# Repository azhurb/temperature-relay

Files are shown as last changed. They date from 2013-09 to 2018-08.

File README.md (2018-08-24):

# Smart outlet

Outlet controlled by a temperature sensor using *ATmega8-P*.  
The heater can be connected to the smart outlet and it will act as a thermostat.

## Demo
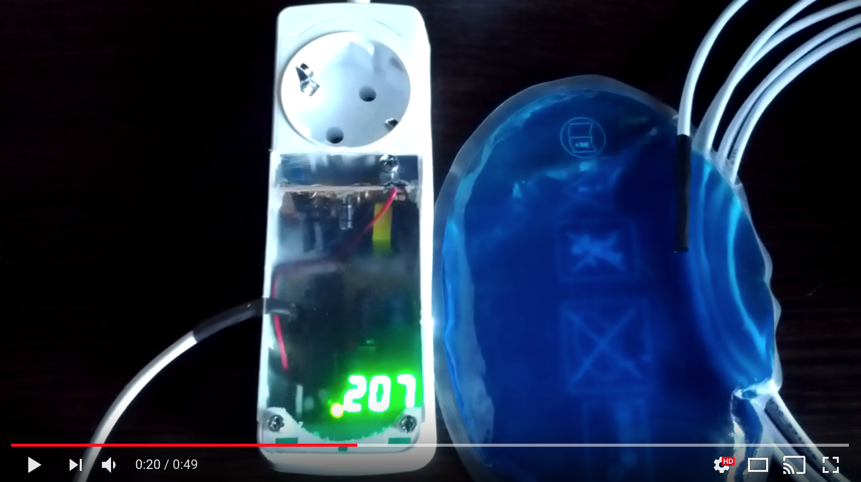
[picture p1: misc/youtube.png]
Outlet controlled by a temperature sensor using ATmega8-P (https://www.youtube.com/watch?v=Genm2P_8VqQ)


## License
Licensed under the MIT license.

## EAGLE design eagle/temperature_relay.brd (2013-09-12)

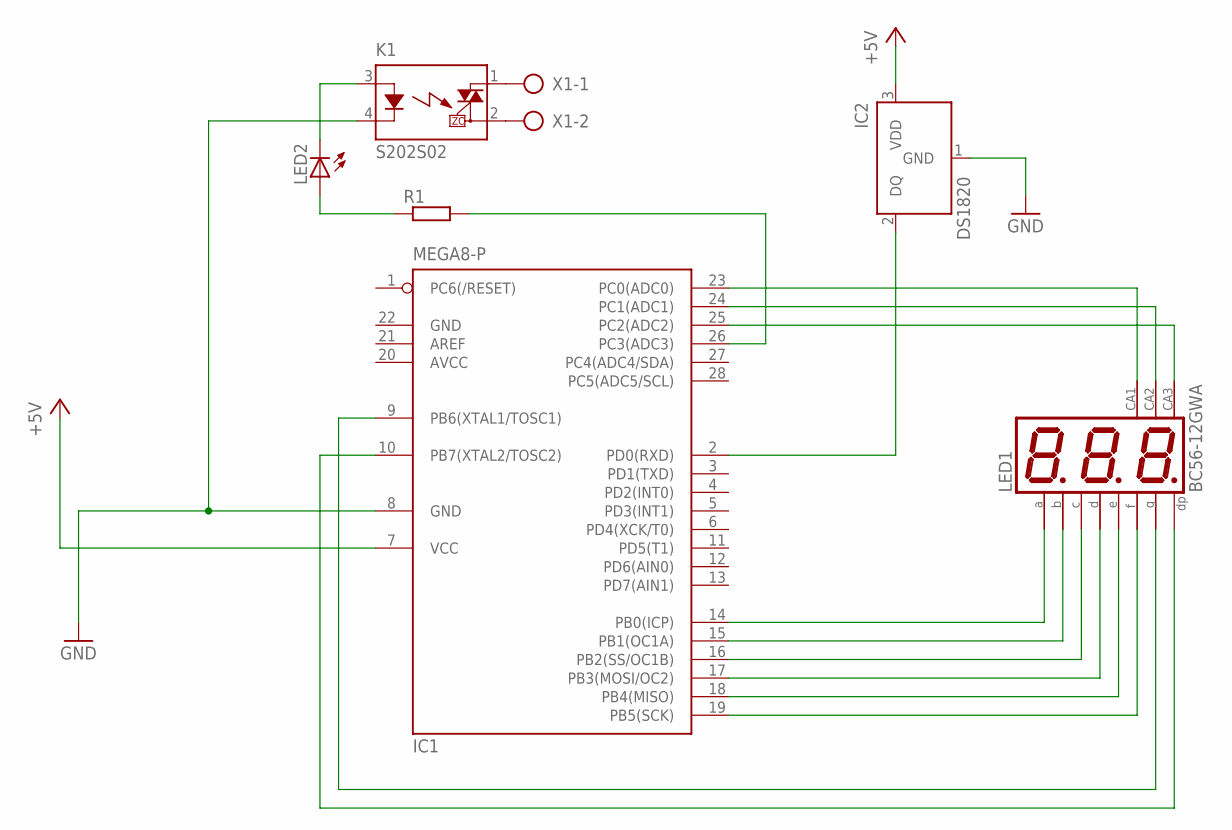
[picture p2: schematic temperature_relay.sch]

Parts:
IC1: MEGA8-P; DIL28-3
IC2: DS1820; TO-92
K1: S202S02
LED1: BC56-12GWA; BX56-12
LED2: LED5MM
R1: R-EU_0309/12; 0309/12
X1: AK300/2

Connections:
+5V: IC1.7 (VCC), IC2.3 (VDD)
AVCC: IC1.20 (AVCC)
GND: IC1.8 (GND), IC1.22 (GND), IC2.1 (GND), K1.4 (K)
unnamed: IC1.23 (PC0(ADC0)), LED1.12 (CA)
unnamed: IC1.24 (PC1(ADC1)), LED1.9 (CA)
unnamed: IC1.25 (PC2(ADC2)), LED1.8 (CA)
unnamed: IC1.14 (PB0(ICP)), LED1.11 (A)
unnamed: IC1.15 (PB1(OC1A)), LED1.7 (B)
unnamed: IC1.16 (PB2(SS/OC1B)), LED1.4 (C)
unnamed: IC1.17 (PB3(MOSI/OC2)), LED1.2 (D)
unnamed: IC1.18 (PB4(MISO)), LED1.1 (E)
unnamed: IC1.19 (PB5(SCK)), LED1.10 (F)
unnamed: IC1.9 (PB6(XTAL1/TOSC1)), LED1.5 (G)
unnamed: IC1.10 (PB7(XTAL2/TOSC2)), LED1.3 (DP)
unnamed: IC1.2 (PD0(RXD)), IC2.2 (DQ)
unnamed: IC1.26 (PC3(ADC3)), R1.2
unnamed: LED2.A, R1.1
unnamed: K1.3 (A), LED2.K (C)
unnamed: K1.2 (DS2), X1.2
unnamed: K1.1 (DS1), X1.1

Board: 2 copper layers, 7 parts (0 on the bottom side), 19 nets, no tracks yet.

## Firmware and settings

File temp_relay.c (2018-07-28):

/***Использование динамической индикации***/
#include <avr/io.h>
#include <avr/interrupt.h>
#include <util/delay.h>

#include "delay.h"
#include "onewire.h"
#include "ds18x20.h"


char SEGMENT[ ] = {0x3F, 0x06, 0x5B, 0x4F, 0x66, 0x6D, 0x7D, 0x07, 0x7F, 0x6F};

volatile unsigned char segcounter = 0;
volatile int display1 = 0;

// Обработчик прерывания по переполнению таймера2
ISR (TIMER2_OVF_vect)
{    
	PORTB = 0x00; //гасим все разряды
	DDRC  = (1 << segcounter) | (PORTC & (1 << PC3)); //выбираем следующий разряд
	switch (segcounter)
	{     
		case 0:
			PORTB = SEGMENT[display1 % 1000 / 100]; // здесь раскладываем число на разряды
			break;
			case 1:
			PORTB = SEGMENT[display1 % 100 / 10] | 0x80;
			break;    
			case 2:
			PORTB = SEGMENT[display1 % 10];
			break;
		}
		if ((segcounter++) > 1) segcounter = 0;    
	}

unsigned char	nDevices;	// количество сенсоров
unsigned char	owDevicesIDs[MAXDEVICES][8];	// Их ID

unsigned char search_ow_devices(void) // поиск всех устройств на шине
{ 
	unsigned char	i;
	unsigned char	id[OW_ROMCODE_SIZE];
	unsigned char	diff, sensors_count;

	sensors_count = 0;

	for( diff = OW_SEARCH_FIRST; diff != OW_LAST_DEVICE && sensors_count < MAXDEVICES ; )
	{ 
		OW_FindROM( &diff, &id[0] );

		if( diff == OW_PRESENCE_ERR ) break;

		if( diff == OW_DATA_ERR )	break;

		for (i=0;i<OW_ROMCODE_SIZE;i++)
			owDevicesIDs[sensors_count][i] = id[i];

		sensors_count++;
	}
	return sensors_count;
}


/***Главная функция***/
int main (void) 
{
	DDRB |= (1 << PB6)|(1 << PB5)|(1 << PB4)|(1 << PB3)|(1 << PB2)|(1 << PB1)|(1 << PB0);
	DDRC |= (1 << PC3)|(1 << PC2)|(1 << PC1)|(1 << PC0);
	PORTB = 0x00;

	DDRD = 0b00000010; PORTD = 0b00000000;

	TIMSK |= (1 << TOIE2); // разрешение прерывания по таймеру2
	TCCR2 |= (1 << CS21); //предделитель на 8

	sei(); //глобально разрешаем прерывания

	timerDelayInit();

	nDevices = search_ow_devices(); // ищем все устройства

	unsigned char	data[2]; // переменная для хранения старшего и младшего байта данных
	char readResult;
	unsigned char	themperature[3]; // в этот массив будет записана температура

	while(1)
	{
		
		for (unsigned char i=0; i<nDevices; i++)
		{
			
			switch (owDevicesIDs[i][0])
			{

				case OW_DS18B20_FAMILY_CODE: { // если найден термодатчик DS18B20

					DS18x20_StartMeasureAddressed(owDevicesIDs[i]); // запускаем измерение
					timerDelayMs(800); // ждем минимум 750 мс, пока конвентируется температура

					readResult = DS18x20_ReadData(owDevicesIDs[i], data);

					if (readResult == 1){
						DS18x20_ConvertToThemperature(data, themperature); // преобразовываем температуру в человекопонятный вид

						display1 = themperature[1]*10 + themperature[2]/10;

						if (display1 < 200){
							PORTC |= (1 << PC3);
						}else if (display1 > 220){
							PORTC &= ~(1 << PC3);
						}
					}

				} break;
			}
		}
	}
}

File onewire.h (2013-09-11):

#ifndef ONEWIRE_H
#define ONEWIRE_H


#include <avr/io.h>


#define true 1
#define false 0

// Максимальное количество устройств на шине
#define MAXDEVICES 8

// Если для эмуляции шины используется USART
#define UART_AS_OneWire

// Если для эмуляции 1-wire не спольльзуется USART, но используется 2 пина (вход и выход)
#define OW_TWO_PINS

#ifdef UART_AS_OneWire
	#define USART_BAUDRATE_57600 (((F_CPU / (57600 * 8UL))) - 1)
	#define USART_BAUDRATE_115200 (((F_CPU / (115200 * 8UL))) - 1)
	#define USART_BAUDRATE_9600 (((F_CPU / (9600 * 8UL))) - 1)
#else
	#include <util/delay.h>
	#define OW_DDR DDRB
	#define OW_PORT PORTB
	#define OW_PIN PINB
	#ifndef OW_TWO_PINS //если используется один пин, укажите его номер
		#define OW_BIT 0
	#else // если используются 2 пина, укажите их номера
		#define OW_BIT_OUT 1
		#define OW_BIT_IN 0
	#endif
#endif

#define OW_CMD_SEARCHROM	0xF0
#define OW_CMD_READROM		0x33
#define OW_CMD_MATCHROM		0x55
#define OW_CMD_SKIPROM		0xCC

#define	OW_SEARCH_FIRST	0xFF		// start new search
#define	OW_PRESENCE_ERR	0xFF
#define	OW_DATA_ERR	    0xFE
#define OW_LAST_DEVICE	0x00		// last device found
//			0x01 ... 0x40: continue searching

#define OW_DS1990_FAMILY_CODE	1
#define OW_DS2405_FAMILY_CODE	5
#define OW_DS2413_FAMILY_CODE	0x3A
#define OW_DS1822_FAMILY_CODE	0x22
#define OW_DS2430_FAMILY_CODE	0x14
#define OW_DS1990_FAMILY_CODE	1
#define OW_DS2431_FAMILY_CODE	0x2d
#define OW_DS18S20_FAMILY_CODE	0x10
#define OW_DS18B20_FAMILY_CODE	0x28
#define OW_DS2433_FAMILY_CODE	0x23

// rom-code size including CRC
#define OW_ROMCODE_SIZE	8

unsigned char OW_Reset(void);
void OW_WriteBit(unsigned char bit);
unsigned char OW_ReadBit(void);
#ifndef UART_AS_OneWire
	unsigned char OW_ReadByte(void);
	void OW_WriteByte(unsigned char byte);
#else
	unsigned char OW_WriteByte(unsigned char byte);
	#define OW_ReadByte() OW_WriteByte(0xFF)
#endif
unsigned char OW_SearchROM( unsigned char diff, unsigned char *id );
void OW_FindROM(unsigned char *diff, unsigned char id[]);
unsigned char OW_ReadROM(unsigned char *buffer);
unsigned char OW_MatchROM(unsigned char *rom);

#endif

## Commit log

2013-09-08 1-wire working?
    [temp_relay.DSN]
2013-09-09 temperature bug
    [temp_relay.DSN]
2013-09-10 finally working ds18b20!
    [temp_relay.DSN]
2013-09-11 Working relay!
    [temp_relay.DSN]
2013-09-12 added eagle files
    [temperature_relay.brd, temperature_relay.sch]
2013-09-18 changed temperature borders
